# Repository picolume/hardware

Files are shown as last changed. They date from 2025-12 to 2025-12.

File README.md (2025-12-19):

# PicoLume Hardware

Hardware designs for the PicoLume wireless LED prop system. All designs are created in KiCad.

## Design Series

### series-prop (Primary)

The primary hardware design for production use. Contains the **PicoLume Board** - a compact control board designed to be installed on each prop in a synchronized LED light show.

**Current Design: receiver-v1**

An RP2040-based control board featuring:

- RP2040 microcontroller with 16MB flash (W25Q16JVS)
- RFM69HCW radio module (915 MHz) for wireless timecode reception
- USB-C connector for programming and show file upload
- Dual power input with automatic switching (LM66200)
- 5V buck converter (AP63205WU) for LED strip power
- Pinout for 0.91" OLED display (I2C)
- Screw terminals for LED strip connection (WS2812B)
- Level shifter (74AHCT1G125) for reliable LED data signal
- Three tactile buttons for configuration
- Onboard WS2812B status LED
- Four M3 mounting holes

The PicoLume Board is the core control component. A complete receiver or transmitter setup requires additional hardware (enclosures, power supplies, antennas, etc.) which are currently being designed.

### series-legacy (Prototypes)

Early prototype designs from the development phase. These boards were used for proof-of-concept testing and firmware development.

**Note:** These designs are prototypes and are not suited for production use.

| Version | Description |
| --- | --- |
| v1 | Initial RFM69-based design |
| v2 | RP2040 with Pi Pico footprint |
| v3 | Refined RP2040 design |
| v4 | RP2350 Experiment |

## Related Repositories

- **firmware/** - Arduino firmware for receiver and remote devices

## License

See [LICENSE](LICENSE) for details.

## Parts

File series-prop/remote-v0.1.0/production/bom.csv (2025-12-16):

Designator | Footprint | Quantity | Value | LCSC Part #
C1, C20, C22 | 0805 | 3 | 22u | C45783
C10, C8 | 0603 | 2 | 1u | C15849
C11, C12, C13, C14, C15, C16, C19, C21, C5, C6, C7, C9 | 0603 | 12 | 100n | C14663
C17 | 0603 | 1 | 10u | C14663
C18, C26 | 1206 | 2 | 10u | C13585
C2, C3 | 0603 | 2 | 30p | C1658
C4 | CP_Elec_8x10 | 1 | 220uF | C2164649
D1 | 0603 | 1 | LED | C2286
D2 | LED_WS2812B-2020_PLCC4_2.0x2.0mm | 1 | WS2812B-2020 | C965555
F1 | 1206 | 1 | Polyfuse | C207036
H1, H2, H3, H4 | MountingHole_3.2mm_M3 | 4 | MountingHole
IC1 | LM66200DRLR | 1 | LM66200DRLR | C3235556
J1, J4 | PinHeader_1x17_P2.54mm_Vertical | 2 | Conn_01x17
J10 | PinHeader_1x03_P2.54mm_Vertical | 1 | Conn_01x03_Pin
J11, J2 | PinHeader_1x04_P2.54mm_Vertical | 2 | Conn_01x04_Pin
J13 | USB_C_Receptacle_HRO_TYPE-C-31-M-12 | 1 | USB_C_Receptacle_USB2.0_16P | C165948
J5 | PinHeader_1x01_P2.54mm_Vertical | 1 | Conn_01x01_Pin
J6 | TerminalBlock_bornier-2_P5.08mm | 1 | Screw_Terminal_01x02
J7 | TerminalBlock_bornier-3_P5.08mm | 1 | Screw_Terminal_01x03
J8 | U.FL_Hirose_U.FL-R-SMT-1_Vertical | 1 | Conn_Coaxial | C88374
J9 | CONN_SM04B-SRSS-TB_JST | 1 | SM04B-SRSS-TB
L2 | L_Sunlord_SWPA4030S | 1 | 4.7u | C57269
R1 | 0603 | 1 | 1k | C21190
R10, R11 | 0603 | 2 | 5.1k | C23186
R15 | 0603 | 1 | 330R | C23138
R2, R21, R6, R7, R8, R9 | 0603 | 6 | 10K | C25804
R3, R4 | 0603 | 2 | 27 | C22941
R5 | 0603 | 1 | 1k
SW1, SW2, SW3 | SW_Tactile_SPST_NO_Straight_CK_PTS636Sx25SMTRLFS | 3 | SW_Push | C609852
U1 | SOT-23-5 | 1 | RT9080-33GJ5 | C841192
U2 | SOIC-8_5.3x5.3mm_P1.27mm | 1 | W25Q16JVS | C131025
U3 | QFN-56-1EP_7x7mm_P0.4mm_EP3.2x3.2mm | 1 | RP2040 | C2040
U4 | HOPERF_RFM9XW_SMD | 1 | RFM69HCW | C2844478
U5 | TSOT-23-6 | 1 | AP63205WU | C2071056
U6 | SOT-23-5 | 1 | 74AHCT1G125 | C7484
U7 | 3544-2 | 1 | 3544-2
Y1 | Crystal_SMD_3225-4Pin_3.2x2.5mm | 1 | Crystal_GND24 | C9002

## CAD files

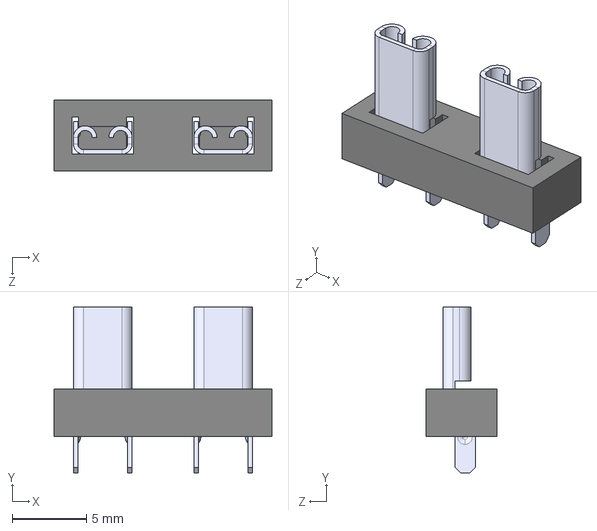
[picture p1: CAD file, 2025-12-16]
series-prop/remote-v0.1.0/3D/3544-2.stp
14.7 x 11.2 x 4.75 mm

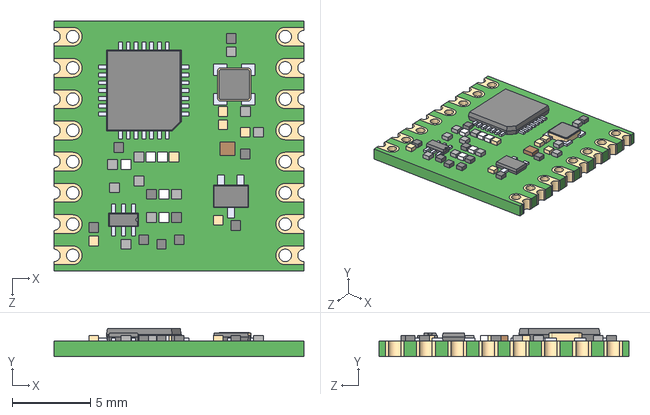
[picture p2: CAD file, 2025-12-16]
series-prop/remote-v0.1.0/3D/RFM69HCW.STEP
16.0 x 1.80 x 16.0 mm

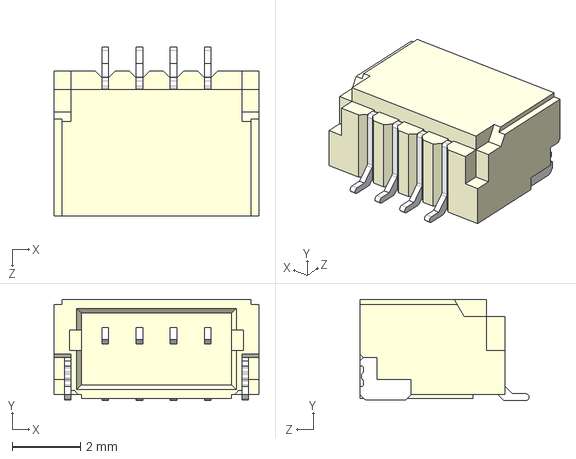
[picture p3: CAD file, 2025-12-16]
series-prop/remote-v0.1.0/3D/SM04B-SRSS-TB.STEP
6.00 x 2.96 x 4.95 mm

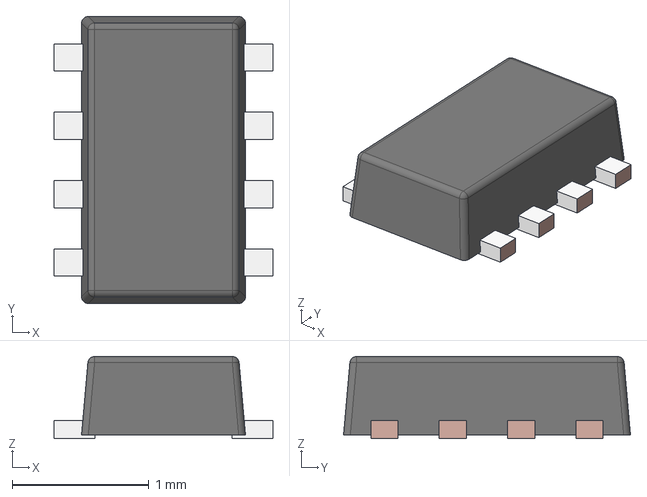
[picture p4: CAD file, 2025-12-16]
series-prop/remote-v0.1.0/3D/LM66200DRLR.stp
1.60 x 2.10 x 0.6 mm
FRAME-DRL0008A
BODY-SOT

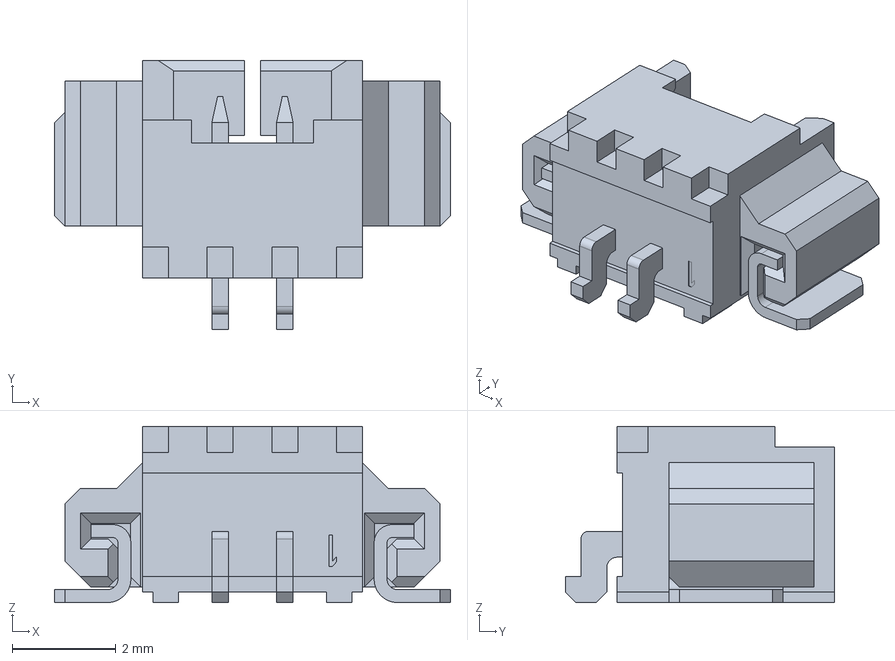
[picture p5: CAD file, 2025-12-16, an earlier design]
series-legacy/v4/3D_Models/53261-0271.stp
7.65 x 5.20 x 3.40 mm

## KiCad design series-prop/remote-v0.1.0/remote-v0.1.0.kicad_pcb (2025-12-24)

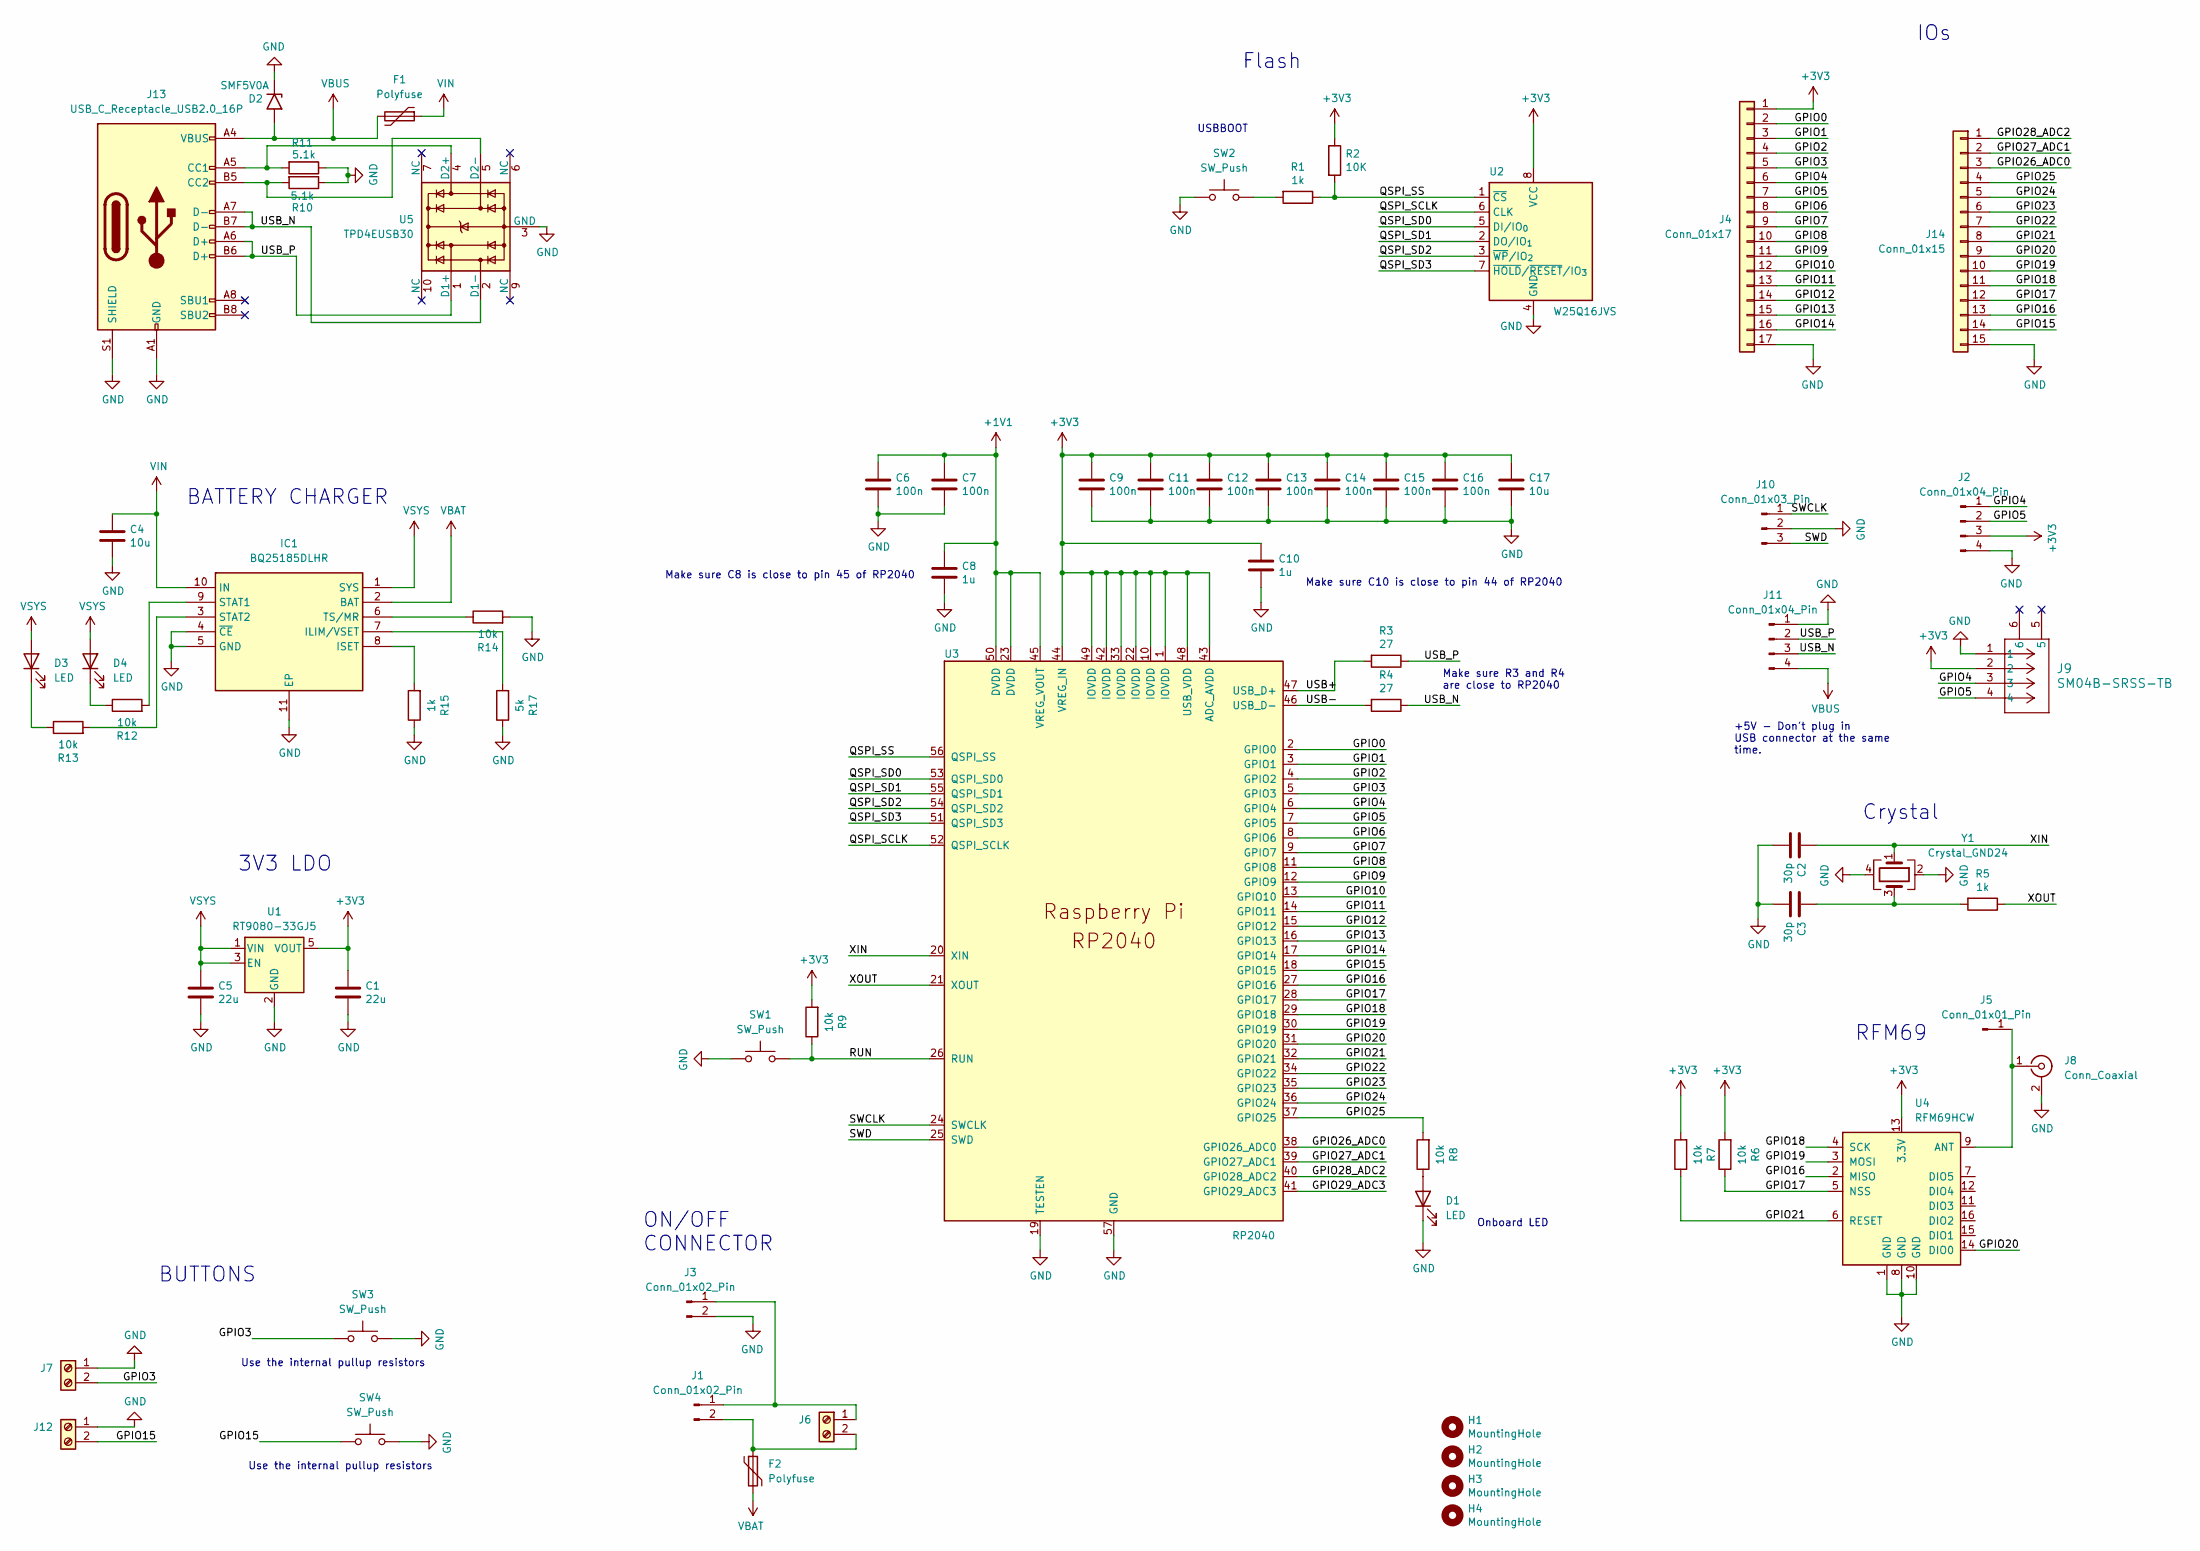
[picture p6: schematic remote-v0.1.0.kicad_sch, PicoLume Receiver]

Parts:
C1, C5: 22u; C_0805_2012Metric; LCSC C45783
C2, C3: 30p; C_0603_1608Metric; LCSC C1658
C4, C17: 10u; C_0603_1608Metric; LCSC C14663
C6, C7, C9, C11, C12, C13, C14, C15, C16: 100n; C_0603_1608Metric; LCSC C14663
C8, C10: 1u; C_0603_1608Metric; LCSC C15849
D1, D3, D4: LED; LED_0603_1608Metric; LCSC C2286
D2: SMF5V0A; D_SMF; LCSC C151296
F1, F2: Polyfuse; Fuse_1210_3225Metric; LCSC C20617440
H1, H2, H3, H4: MountingHole; MountingHole_3.2mm_M3
IC1: BQ25185DLHR; SON40P220X200X80-11N; Mouser Part Number 595-BQ25185DLHR
J1: Conn_01x02_Pin; PinHeader_1x02_P2.54mm_Vertical
J2, J11: Conn_01x04_Pin; PinHeader_1x04_P2.54mm_Vertical
J3: Conn_01x02_Pin; JST_PH_S2B-PH-K_1x02_P2.00mm_Horizontal
J4: Conn_01x17; PinHeader_1x17_P2.54mm_Vertical
J5: Conn_01x01_Pin; PinHeader_1x01_P2.54mm_Vertical
J6, J7, J12: Screw_Terminal_01x02; TerminalBlock_bornier-2_P5.08mm
J8: Conn_Coaxial; U.FL_Hirose_U.FL-R-SMT-1_Vertical; LCSC C88374
J9: SM04B-SRSS-TB; CONN_SM04B-SRSS-TB_JST
J10: Conn_01x03_Pin; PinHeader_1x03_P2.54mm_Vertical
J13: USB_C_Receptacle_USB2.0_16P; USB_C_Receptacle_HRO_TYPE-C-31-M-12; LCSC C165948
J14: Conn_01x15; PinHeader_1x15_P2.54mm_Vertical
R1, R15: 1k; R_0603_1608Metric; LCSC C21190
R2: 10K; R_0603_1608Metric; LCSC C25804
R3, R4: 27; R_0603_1608Metric; LCSC C22941
R5: 1k; R_0603_1608Metric
R6, R7, R8, R9, R12, R13, R14: 10k; R_0603_1608Metric; LCSC C25804
R10, R11: 5.1k; R_0603_1608Metric; LCSC C23186
R17: 5k; R_0603_1608Metric; LCSC C166926
SW1, SW2, SW3, SW4: SW_Push; SW_Tactile_SPST_NO_Straight_CK_PTS636Sx25SMTRLFS; LCSC C609852
U1: RT9080-33GJ5; SOT-23-5; LCSC C841192
U2: W25Q16JVS; SOIC-8_5.3x5.3mm_P1.27mm; LCSC C131025
U3: RP2040; QFN-56-1EP_7x7mm_P0.4mm_EP3.2x3.2mm; LCSC C2040
U4: RFM69HCW; HOPERF_RFM9XW_SMD; LCSC C2844478
U5: TPD4EUSB30; USON-10_2.5x1.0mm_P0.5mm; LCSC C90627
Y1: Crystal_GND24; Crystal_SMD_3225-4Pin_3.2x2.5mm; LCSC C9002

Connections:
+1V1: C6.1, C7.1, C8.1, U3.23 (DVDD), U3.45 (VREG_VOUT), U3.50 (DVDD)
+3V3: C1.1, C9.1, C10.1, C11.1, C12.1, C13.1, C14.1, C15.1, C16.1, C17.1, J2.3, J4.1, J9.2, R2.1, R6.2, R7.2, R9.2, U1.5 (VOUT), U2.8 (VCC), U3.1 (IOVDD), U3.10 (IOVDD), U3.22 (IOVDD), U3.33 (IOVDD), U3.42 (IOVDD), U3.43 (ADC_AVDD), U3.44 (VREG_IN), U3.48 (USB_VDD), U3.49 (IOVDD), U4.13 (3.3V)
/GPIO0: J4.2, U3.2 (GPIO0)
/GPIO1: J4.3, U3.3 (GPIO1)
/GPIO2: J4.4, U3.4 (GPIO2)
/GPIO3: J4.5, J7.2, SW3.2, U3.5 (GPIO3)
/GPIO4: J2.1, J4.6, J9.3, U3.6 (GPIO4)
/GPIO5: J2.2, J4.7, J9.4, U3.7 (GPIO5)
/GPIO6: J4.8, U3.8 (GPIO6)
/GPIO7: J4.9, U3.9 (GPIO7)
/GPIO8: J4.10, U3.11 (GPIO8)
/GPIO9: J4.11, U3.12 (GPIO9)
/GPIO10: J4.12, U3.13 (GPIO10)
/GPIO11: J4.13, U3.14 (GPIO11)
/GPIO12: J4.14, U3.15 (GPIO12)
/GPIO13: J4.15, U3.16 (GPIO13)
/GPIO14: J4.16, U3.17 (GPIO14)
/GPIO15: J12.2, J14.14, SW4.2, U3.18 (GPIO15)
/GPIO16: J14.13, U3.27 (GPIO16), U4.2 (MISO)
/GPIO17: J14.12, R6.1, U3.28 (GPIO17), U4.5 (NSS)
/GPIO18: J14.11, U3.29 (GPIO18), U4.4 (SCK)
/GPIO19: J14.10, U3.30 (GPIO19), U4.3 (MOSI)
/GPIO20: J14.9, U3.31 (GPIO20), U4.14 (DIO0)
/GPIO21: J14.8, R7.1, U3.32 (GPIO21), U4.6 (RESET)
/GPIO22: J14.7, U3.34 (GPIO22)
/GPIO23: J14.6, U3.35 (GPIO23)
/GPIO24: J14.5, U3.36 (GPIO24)
/GPIO25: J14.4, R8.2, U3.37 (GPIO25)
/GPIO26_ADC0: J14.3, U3.38 (GPIO26_ADC0)
/GPIO27_ADC1: J14.2, U3.39 (GPIO27_ADC1)
/GPIO28_ADC2: J14.1, U3.40 (GPIO28_ADC2)
/GPIO29_ADC3: U3.41 (GPIO29_ADC3)
/QSPI_SCLK: U2.6 (CLK), U3.52 (QSPI_SCLK)
/QSPI_SD0: U2.5 (DI/IO_{0}), U3.53 (QSPI_SD0)
/QSPI_SD1: U2.2 (DO/IO_{1}), U3.55 (QSPI_SD1)
/QSPI_SD2: U2.3 (~WP/IO_{2}), U3.54 (QSPI_SD2)
/QSPI_SD3: U2.7 (~HOLD/~RESET/IO_{3}), U3.51 (QSPI_SD3)
/QSPI_SS: R1.1, R2.2, U2.1 (~CS), U3.56 (QSPI_SS)
/RUN: R9.1, SW1.2, U3.26 (RUN)
/SWCLK: J10.1, U3.24 (SWCLK)
/SWD: J10.3, U3.25 (SWD)
/USB+: R3.2, U3.47 (USB_D+)
/USB-: R4.2, U3.46 (USB_D-)
/USB_N: J11.3, J13.A7 (D-), J13.B7 (D-), R4.1, U5.2 (D1-)
/USB_P: J11.2, J13.A6 (D+), J13.B6 (D+), R3.1, U5.1 (D1+)
/XIN: C2.1, U3.20 (XIN), Y1.1
/XOUT: R5.1, U3.21 (XOUT)
GND: C1.2, C2.2, C3.2, C4.2, C5.2, C6.2, C7.2, C8.2, C9.2, C10.2, C11.2, C12.2, C13.2, C14.2, C15.2, C16.2, C17.2, D1.1 (K), D2.1 (A1), IC1.4 (~CE), IC1.5 (GND), IC1.11 (EP), J2.4, J3.2, J4.17, J7.1, J8.2 (Ext), J9.1, J10.2, J11.1, J12.1, J13.A1 (GND), J13.A12 (GND), J13.B1 (GND), J13.B12 (GND), J13.S1 (SHIELD), J14.15, R10.1, R11.1, R14.2, R15.1, R17.1, SW1.1, SW2.1, SW3.1, SW4.1, U1.2 (GND), U2.4 (GND), U3.19 (TESTEN), U3.57 (GND), U4.1 (GND), U4.8 (GND), U4.10 (GND), U5.3 (GND), U5.8 (GND), Y1.2, Y1.4
unnamed: C3.1, R5.2, Y1.3
unnamed: D1.2 (A), R8.1
unnamed: D3.1 (K), R13.1
unnamed: D4.1 (K), R12.1
unnamed: IC1.7 (ILIM/VSET), R17.2
unnamed: IC1.8 (ISET), R15.2
unnamed: IC1.9 (STAT1), R12.2
unnamed: IC1.3 (STAT2), R13.2
unnamed: IC1.6 (TS/MR), R14.1
unnamed: J1.1, J3.1, J6.1
unnamed: F2.1, J1.2, J6.2
unnamed: J5.1, J8.1 (In), U4.9 (ANT)
unnamed: J13.A5 (CC1), R11.2, U5.4 (D2+)
unnamed: J13.B5 (CC2), R10.2, U5.5 (D2-)
unnamed: R1.2, SW2.2
VBAT: F2.2, IC1.2 (BAT)
VBUS: D2.2 (A2), F1.2, J11.4, J13.A4 (VBUS), J13.A9 (VBUS), J13.B4 (VBUS), J13.B9 (VBUS)
VIN: C4.1, F1.1, IC1.10 (IN)
VSYS: C5.1, D3.2 (A), D4.2 (A), IC1.1 (SYS), U1.1 (VIN), U1.3 (EN)

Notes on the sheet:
Use the internal pullup resistors
RFM69
IOs
Crystal
Make sure C8 is close to pin 45 of RP2040
+5V - Don't plug in USB connector at the same time.
BUTTONS
USBBOOT
Make sure C10 is close to pin 44 of RP2040
ON/OFF CONNECTOR
Onboard LED
BATTERY CHARGER
3V3 LDO
Make sure R3 and R4 are close to RP2040
Flash

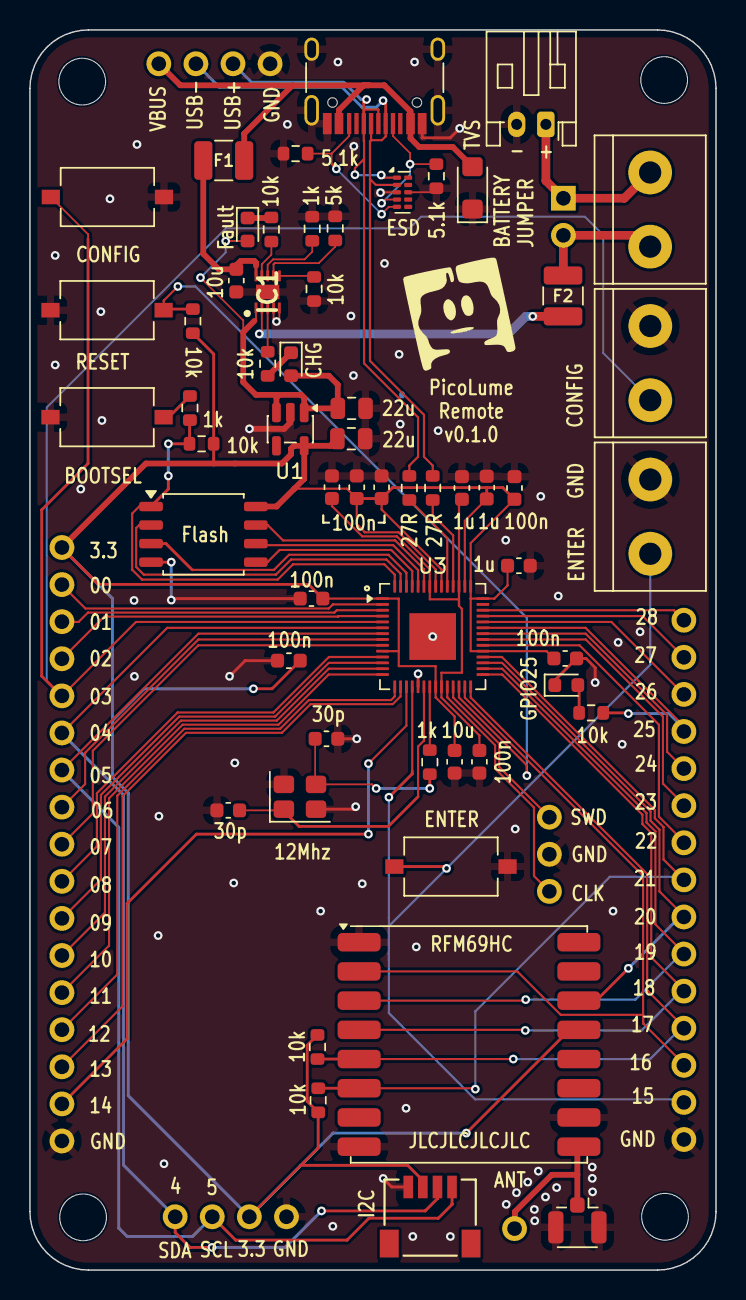
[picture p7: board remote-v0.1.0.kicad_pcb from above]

Board: 2 copper layers, 47.0 x 84.9 mm, 68 parts (0 on the bottom side), 66 nets.

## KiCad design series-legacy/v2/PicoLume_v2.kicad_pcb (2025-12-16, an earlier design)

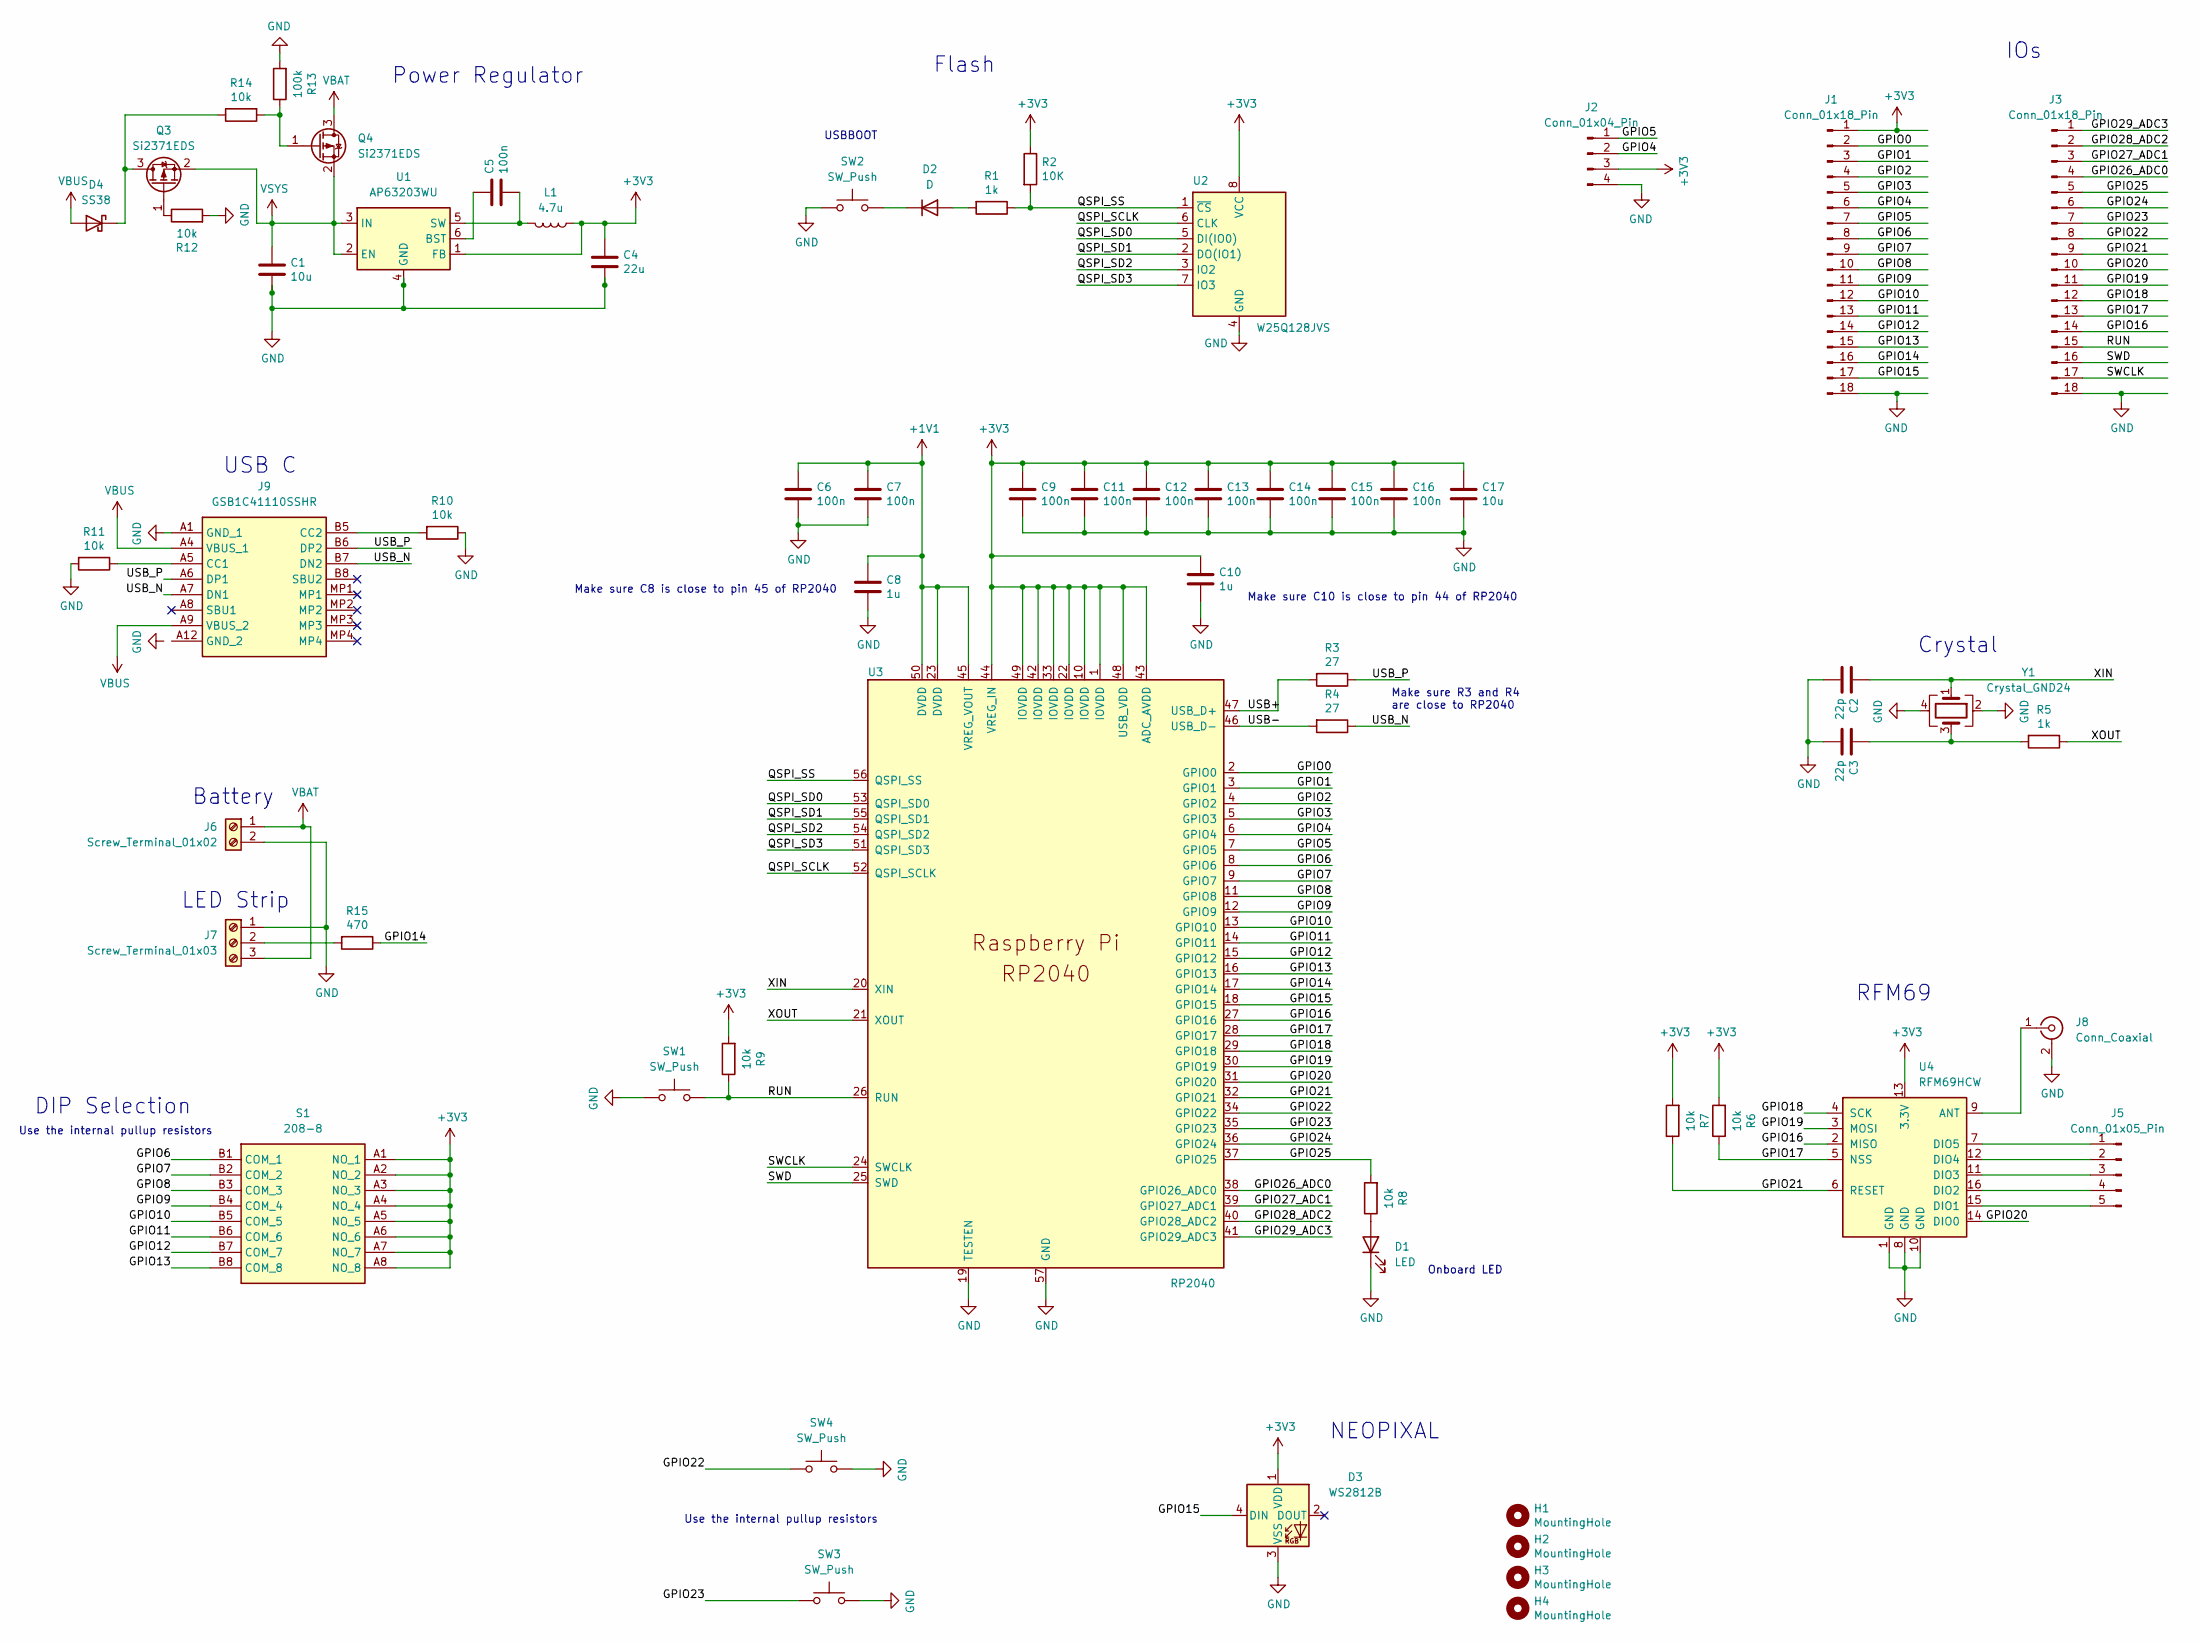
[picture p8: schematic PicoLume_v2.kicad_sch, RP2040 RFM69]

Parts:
C1, C17: 10u; C_0603_1608Metric
C2, C3: 22p; C_0603_1608Metric
C4: 22u; C_0603_1608Metric
C5, C6, C7, C9, C11, C12, C13, C14, C15, C16: 100n; C_0603_1608Metric
C8, C10: 1u; C_0603_1608Metric
D1: LED; LED_0603_1608Metric
D2: D; D_0603_1608Metric
D3: WS2812B; LED_WS2812B_PLCC4_5.0x5.0mm_P3.2mm
D4: SS38; D_SMA
H1, H2, H3, H4: MountingHole; MountingHole_2.7mm_M2.5
J1, J3: Conn_01x18_Pin; PinHeader_1x18_P2.54mm_Vertical
J2: Conn_01x04_Pin; PinHeader_1x04_P2.54mm_Vertical
J5: Conn_01x05_Pin; PinHeader_1x05_P2.54mm_Vertical
J6: Screw_Terminal_01x02; TerminalBlock_bornier-2_P5.08mm
J7: Screw_Terminal_01x03; TerminalBlock_bornier-3_P5.08mm
J8: Conn_Coaxial; U.FL_Molex_MCRF_73412-0110_Vertical
J9: GSB1C41110SSHR; Manufacturer_Part_Number GSB1C41110SSHR
L1: 4.7u; VLS5045EX330M
Q3, Q4: Si2371EDS; SOT-23
R1, R5: 1k; R_0603_1608Metric
R2: 10K; R_0603_1608Metric
R3, R4: 27; R_0603_1608Metric
R6, R7, R8, R9, R10, R11, R12, R14: 10k; R_0603_1608Metric
R13: 100k; R_0603_1608Metric
R15: 470; R_0603_1608Metric
S1: 208-8; 2088; Mouser Part Number 774-2088
SW1, SW2, SW3, SW4: SW_Push; FSMH
U1: AP63203WU; TSOT-23-6
U2: W25Q128JVS; SOIC-8_5.23x5.23mm_P1.27mm
U3: RP2040; RP2040-QFN-56
U4: RFM69HCW; MOD_COM-13909
Y1: Crystal_GND24; ABM810000MHZ12D2W

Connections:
+1V1: C6.1, C7.1, C8.1, U3.23 (DVDD), U3.45 (VREG_VOUT), U3.50 (DVDD)
+3V3: C4.1, C9.1, C10.1, C11.1, C12.1, C13.1, C14.1, C15.1, C16.1, C17.1, D3.1 (VDD), J1.1, J2.3, L1.1, R2.1, R6.2, R7.2, R9.2, S1.A1 (NO_1), S1.A2 (NO_2), S1.A3 (NO_3), S1.A4 (NO_4), S1.A5 (NO_5), S1.A6 (NO_6), S1.A7 (NO_7), S1.A8 (NO_8), U1.1 (FB), U2.8 (VCC), U3.1 (IOVDD), U3.10 (IOVDD), U3.22 (IOVDD), U3.33 (IOVDD), U3.42 (IOVDD), U3.43 (ADC_AVDD), U3.44 (VREG_IN), U3.48 (USB_VDD), U3.49 (IOVDD), U4.13 (3.3V)
/GPIO0: J1.2, U3.2 (GPIO0)
/GPIO1: J1.3, U3.3 (GPIO1)
/GPIO2: J1.4, U3.4 (GPIO2)
/GPIO3: J1.5, U3.5 (GPIO3)
/GPIO4: J1.6, J2.2, U3.6 (GPIO4)
/GPIO5: J1.7, J2.1, U3.7 (GPIO5)
/GPIO6: J1.8, S1.B1 (COM_1), U3.8 (GPIO6)
/GPIO7: J1.9, S1.B2 (COM_2), U3.9 (GPIO7)
/GPIO8: J1.10, S1.B3 (COM_3), U3.11 (GPIO8)
/GPIO9: J1.11, S1.B4 (COM_4), U3.12 (GPIO9)
/GPIO10: J1.12, S1.B5 (COM_5), U3.13 (GPIO10)
/GPIO11: J1.13, S1.B6 (COM_6), U3.14 (GPIO11)
/GPIO12: J1.14, S1.B7 (COM_7), U3.15 (GPIO12)
/GPIO13: J1.15, S1.B8 (COM_8), U3.16 (GPIO13)
/GPIO14: J1.16, R15.1, U3.17 (GPIO14)
/GPIO15: D3.4 (DIN), J1.17, U3.18 (GPIO15)
/GPIO16: J3.14, U3.27 (GPIO16), U4.2 (MISO)
/GPIO17: J3.13, R6.1, U3.28 (GPIO17), U4.5 (NSS)
/GPIO18: J3.12, U3.29 (GPIO18), U4.4 (SCK)
/GPIO19: J3.11, U3.30 (GPIO19), U4.3 (MOSI)
/GPIO20: J3.10, U3.31 (GPIO20), U4.14 (DIO0)
/GPIO21: J3.9, R7.1, U3.32 (GPIO21), U4.6 (RESET)
/GPIO22: J3.8, SW4.2, U3.34 (GPIO22)
/GPIO23: J3.7, SW3.2, U3.35 (GPIO23)
/GPIO24: J3.6, U3.36 (GPIO24)
/GPIO25: J3.5, R8.2, U3.37 (GPIO25)
/GPIO26_ADC0: J3.4, U3.38 (GPIO26_ADC0)
/GPIO27_ADC1: J3.3, U3.39 (GPIO27_ADC1)
/GPIO28_ADC2: J3.2, U3.40 (GPIO28_ADC2)
/GPIO29_ADC3: J3.1, U3.41 (GPIO29_ADC3)
/QSPI_SCLK: U2.6 (CLK), U3.52 (QSPI_SCLK)
/QSPI_SD0: U2.5 (DI(IO0)), U3.53 (QSPI_SD0)
/QSPI_SD1: U2.2 (DO(IO1)), U3.55 (QSPI_SD1)
/QSPI_SD2: U2.3 (IO2), U3.54 (QSPI_SD2)
/QSPI_SD3: U2.7 (IO3), U3.51 (QSPI_SD3)
/QSPI_SS: R1.1, R2.2, U2.1 (~CS), U3.56 (QSPI_SS)
/RUN: J3.15, R9.1, SW1.2, U3.26 (RUN)
/SWCLK: J3.17, U3.24 (SWCLK)
/SWD: J3.16, U3.25 (SWD)
/USB+: R3.2, U3.47 (USB_D+)
/USB-: R4.2, U3.46 (USB_D-)
/USB_N: J9.A7 (DN1), J9.B7 (DN2), R4.1
/USB_P: J9.A6 (DP1), J9.B6 (DP2), R3.1
/XIN: C2.1, U3.20 (XIN), Y1.1
/XOUT: R5.1, U3.21 (XOUT)
GND: C1.2, C2.2, C3.2, C4.2, C6.2, C7.2, C8.2, C9.2, C10.2, C11.2, C12.2, C13.2, C14.2, C15.2, C16.2, C17.2, D1.1 (K), D3.3 (VSS), J1.18, J2.4, J3.18, J6.2, J7.1, J8.2 (Ext), J9.A1 (GND_1), R10.1, R11.2, R12.2, R13.2, SW1.1, SW2.1, SW3.1, SW4.1, U1.4 (GND), U2.4 (GND), U3.19 (TESTEN), U3.57 (GND), U4.1 (GND), U4.8 (GND), U4.10 (GND), Y1.2, Y1.4
unnamed: C3.1, R5.2, Y1.3
unnamed: D1.2 (A), R8.1
unnamed: D2.2 (A), R1.2
unnamed: D2.1 (K), SW2.2
unnamed: D4.1 (K), Q3.3 (D), R14.1
unnamed: J5.1, U4.7 (DIO5)
unnamed: J5.2, U4.12 (DIO4)
unnamed: J5.3, U4.11 (DIO3)
unnamed: J5.4, U4.16 (DIO2)
unnamed: J5.5, U4.15 (DIO1)
unnamed: J7.2, R15.2
unnamed: J8.1 (In), U4.9 (ANT)
unnamed: J9.A5 (CC1), R11.1
unnamed: J9.B5 (CC2), R10.2
unnamed: Q3.1 (G), R12.1
unnamed: Q4.1 (G), R13.1, R14.2
unnamed: C5.1, U1.6 (BST)
unnamed: C5.2, L1.2, U1.5 (SW)
VBAT: J6.1, J7.3, Q4.3 (D)
VBUS: D4.2 (A), J9.A4 (VBUS_1), J9.A9 (VBUS_2)
VSYS: C1.1, Q3.2 (S), Q4.2 (S), U1.2 (EN), U1.3 (IN)

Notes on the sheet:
DIP Selection
Use the internal pullup resistors
NEOPIXAL
RFM69
IOs
Crystal
USB C
Make sure C8 is close to pin 45 of RP2040
Battery
LED Strip
USBBOOT
Power Regulator
Make sure C10 is close to pin 44 of RP2040
Onboard LED
Make sure R3 and R4 are close to RP2040
Flash

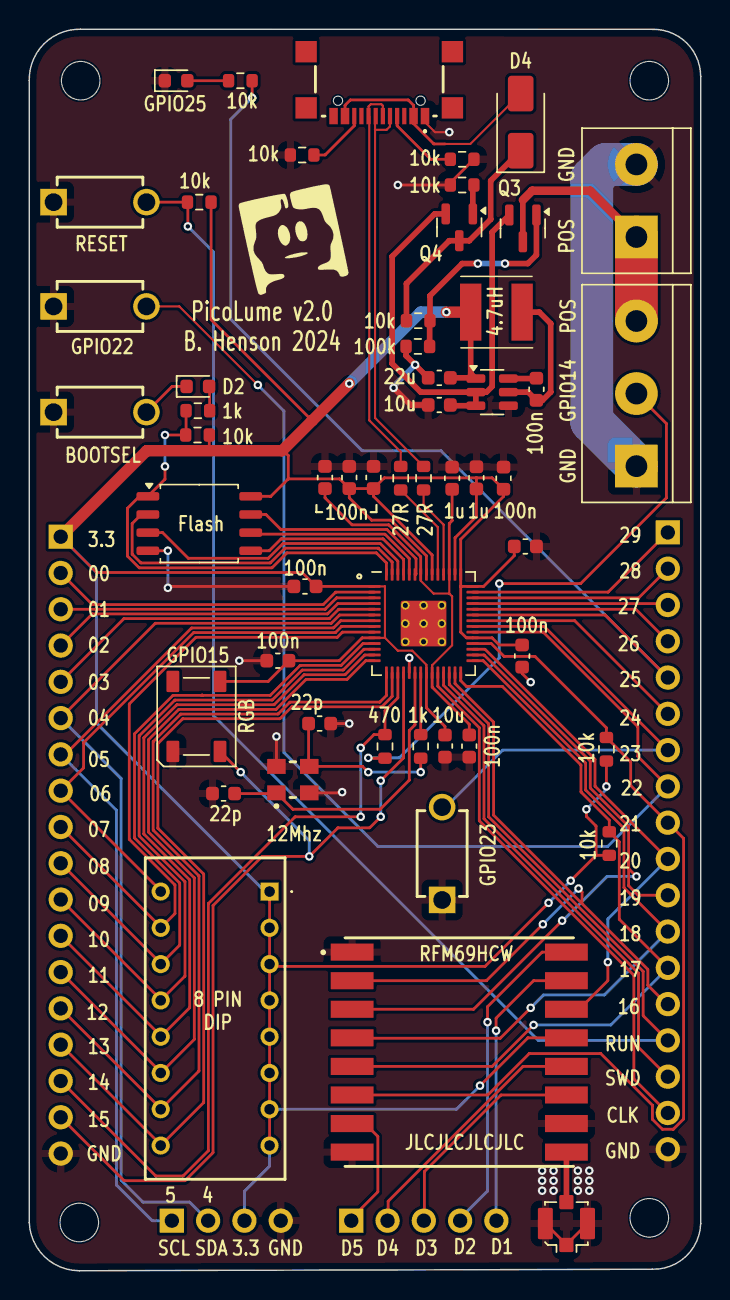
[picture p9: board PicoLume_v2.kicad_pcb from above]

Board: 2 copper layers, 47.0 x 86.9 mm, 61 parts (0 on the bottom side), 69 nets.

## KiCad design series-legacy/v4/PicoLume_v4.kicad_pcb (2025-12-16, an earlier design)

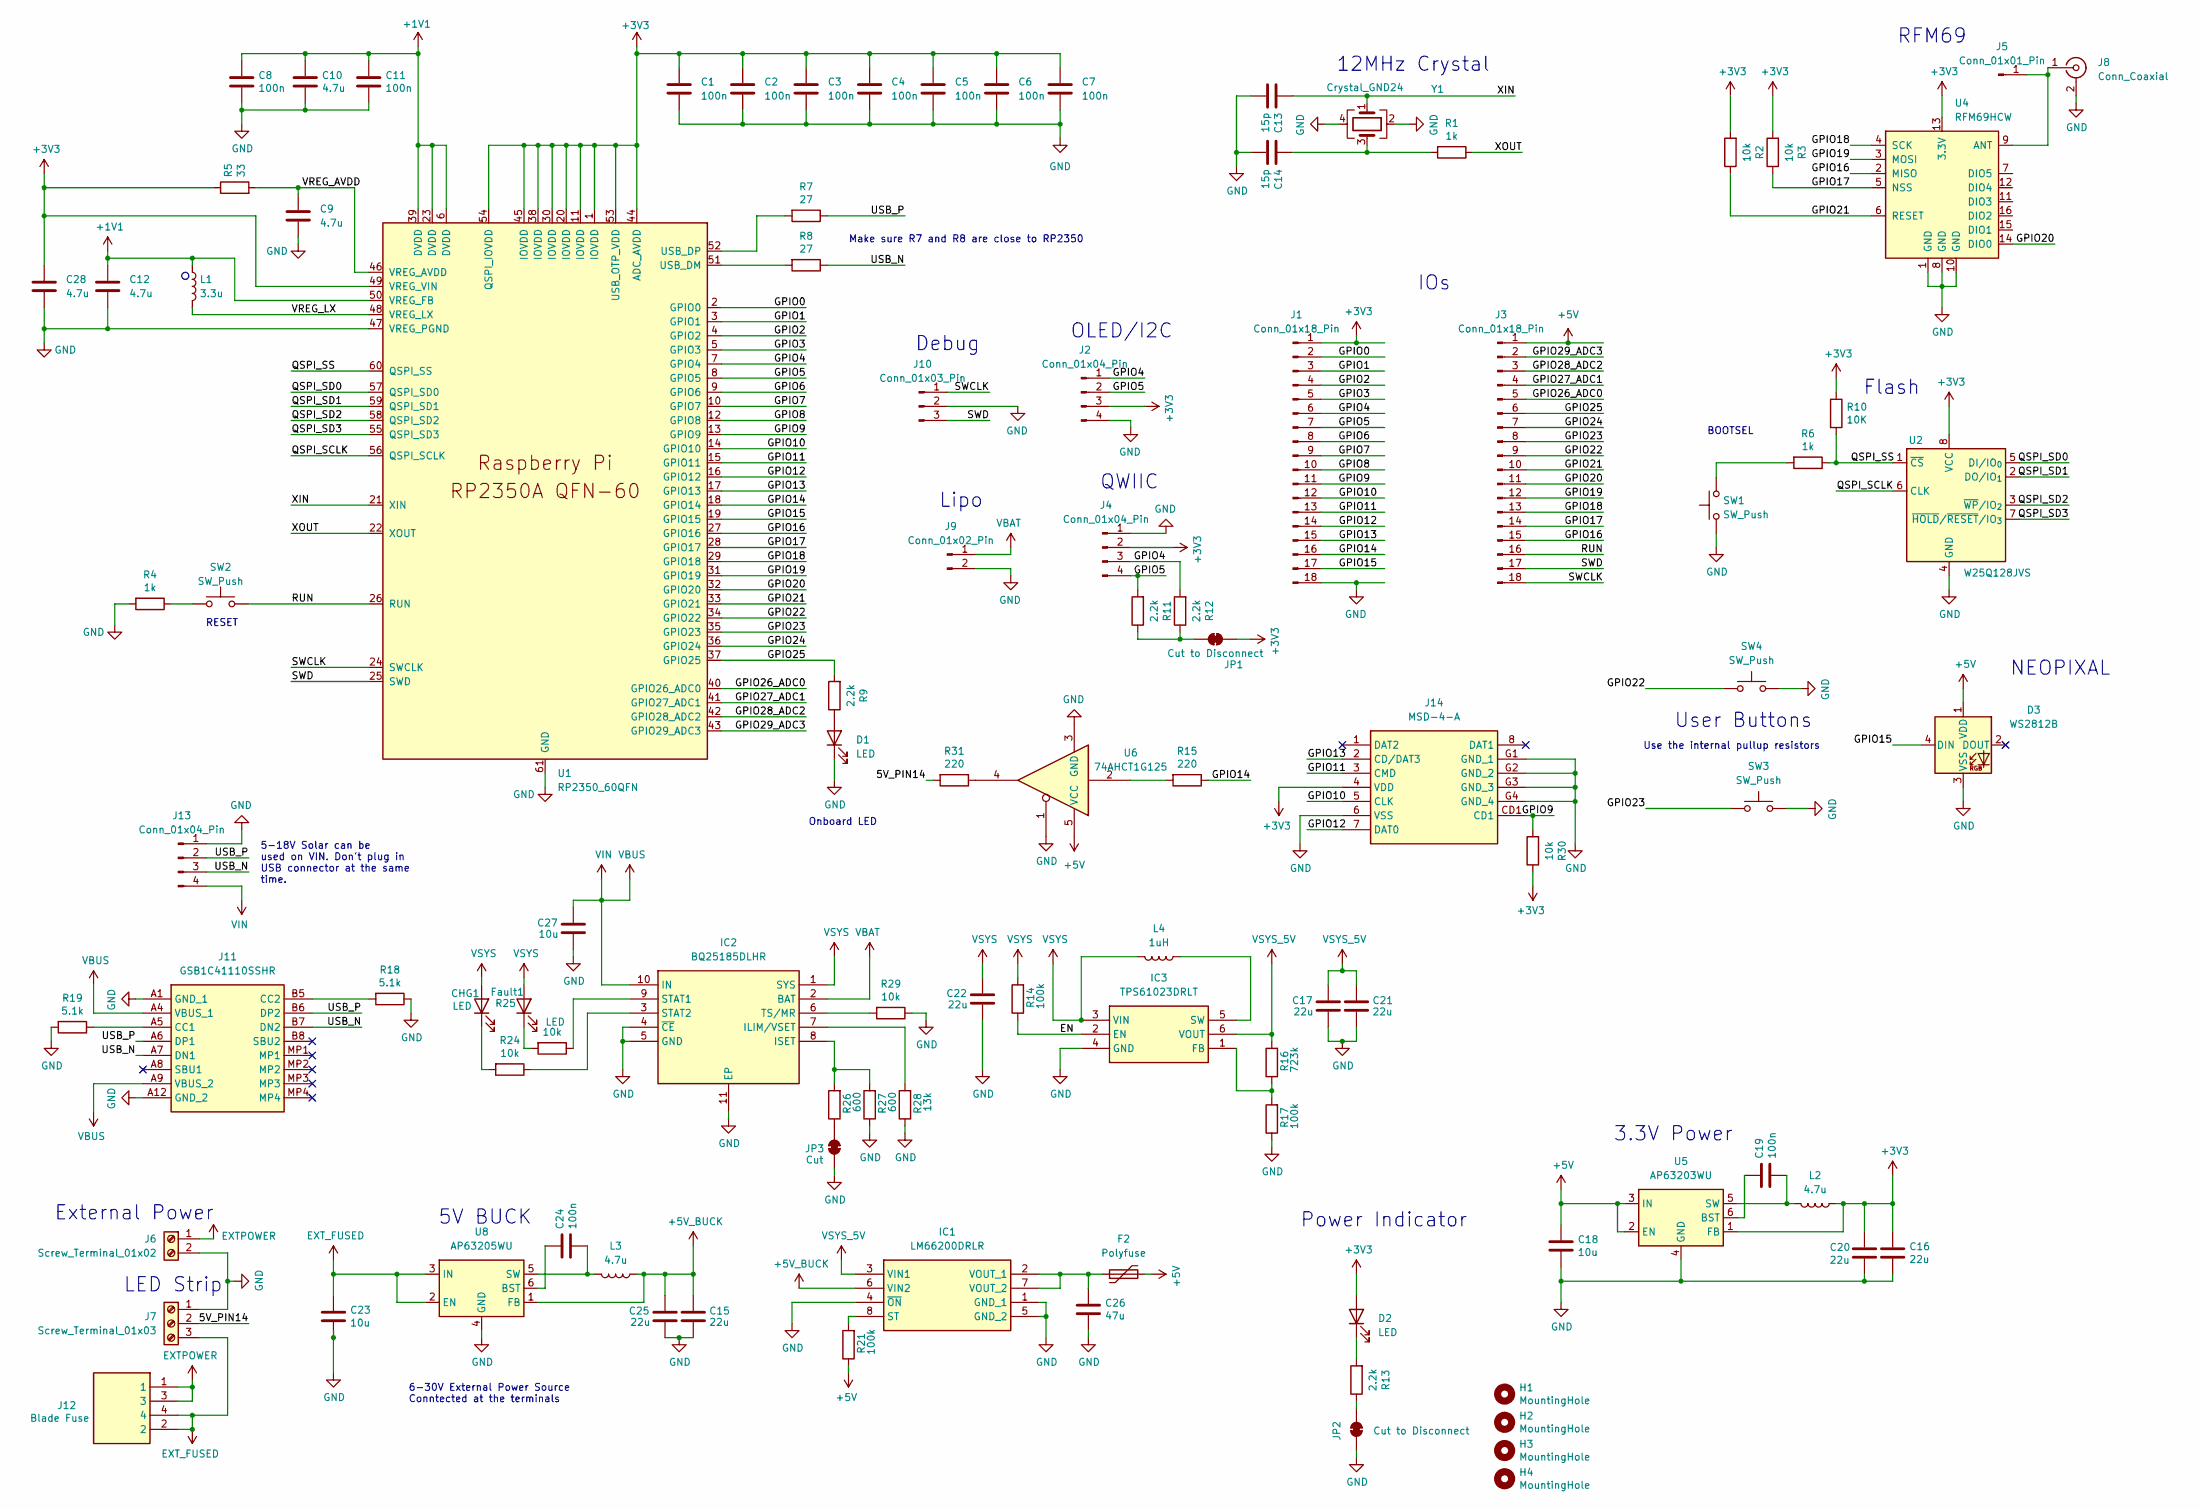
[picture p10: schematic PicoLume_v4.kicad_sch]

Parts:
C1, C2, C3, C4, C5, C6, C7, C8, C11, C19, C24: 100n; C_0603_1608Metric
C9, C10, C12, C28: 4.7u; C_0603_1608Metric
C13, C14: 15p; C_0603_1608Metric
C15, C16, C17, C20, C21, C22, C25: 22u; C_0805_2012Metric
C18: 10u; C_0805_2012Metric
C23: 10u; C_1206_3216Metric
C26: 47u; C_1206_3216Metric
C27: 10u; C_0603_1608Metric
CHG1: LED; LED_0603_1608Metric
D1, D2: LED; LED_0603_1608Metric
D3: WS2812B; INPI15TAT5R5G5B
F2: Polyfuse; 1206L075132WR
Fault1: LED; LED_0603_1608Metric
H1, H2, H3, H4: MountingHole; MountingHole_3.2mm_M3
IC1: LM66200DRLR; SOTFL50P160X60-8N; Mouser Part Number 595-LM66200DRLR
IC2: BQ25185DLHR; SON40P220X200X80-11N; Mouser Part Number 595-BQ25185DLHR
IC3: TPS61023DRLT; SOTFL50P160X60-6N; Mouser Part Number 595-TPS61023DRLT
J1, J3: Conn_01x18_Pin; PinHeader_1x18_P2.54mm_Vertical
J2, J13: Conn_01x04_Pin; PinHeader_1x04_P2.54mm_Vertical
J4: Conn_01x04_Pin; JST_SH_SM04B-SRSS-TB_1x04-1MP_P1.00mm_Horizontal
J5: Conn_01x01_Pin; PinHeader_1x01_P2.54mm_Vertical
J6: Screw_Terminal_01x02; TerminalBlock_bornier-2_P5.08mm
J7: Screw_Terminal_01x03; TerminalBlock_bornier-3_P5.08mm
J8: Conn_Coaxial; U.FL_Molex_MCRF_73412-0110_Vertical
J9: Conn_01x02_Pin; JST_PH_S2B-PH-K_1x02_P2.00mm_Horizontal
J10: Conn_01x03_Pin; JST_SH_BM03B-SRSS-TB_1x03-1MP_P1.00mm_Vertical
J11: GSB1C41110SSHR; Manufacturer_Part_Number GSB1C41110SSHR
J12: Blade Fuse; 35222; Mouser Part Number 534-3522-2
J14: MSD-4-A; MSD4A; Mouser Part Number 179-MSD-4-A
JP1, JP2: Cut to Disconnect; SolderJumper-2_P1.3mm_Bridged_RoundedPad1.0x1.5mm
JP3: Cut; SolderJumper-2_P1.3mm_Bridged_RoundedPad1.0x1.5mm
L1: 3.3u; AOTAB201610S3R3101T
L2, L3: 4.7u; L_1210_3225Metric
L4: 1uH; L_1210_3225Metric
R1, R4, R6: 1k; R_0603_1608Metric
R2, R3, R24, R25, R29, R30: 10k; R_0603_1608Metric
R5: 33; R_0603_1608Metric
R7, R8: 27; R_0603_1608Metric
R9, R11, R12, R13: 2.2k; R_0603_1608Metric
R10: 10K; R_0603_1608Metric
R14, R17, R21: 100k; R_0603_1608Metric
R15, R31: 220; R_0603_1608Metric
R16: 723k; R_0603_1608Metric
R18, R19: 5.1k; R_0603_1608Metric
R26, R27: 600; R_0603_1608Metric
R28: 13k; R_0603_1608Metric
SW1, SW2, SW3, SW4: SW_Push; FSMH
U1: RP2350_60QFN; RP2350-QFN-60-1EP_7x7_P0.4mm_EP3.4x3.4mm_ThermalVias
U2: W25Q128JVS; SOIC-8_5.3x5.3mm_P1.27mm
U4: RFM69HCW; MOD_COM-13909
U5: AP63203WU; TSOT-23-6
U6: 74AHCT1G125; SOT-25
U8: AP63205WU; TSOT-23-6
Y1: Crystal_GND24; ABM8272T3

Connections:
+1V1: C8.1, C10.1, C11.1, C12.1, L1.1, U1.6 (DVDD), U1.23 (DVDD), U1.39 (DVDD), U1.50 (VREG_FB)
+3V3: C1.1, C2.1, C3.1, C4.1, C5.1, C6.1, C7.1, C16.1, C20.1, C28.1, D2.2 (A), J1.1, J2.3, J4.2, J14.4 (VDD), JP1.2 (B), L2.1, R2.2, R3.2, R5.1, R10.1, R30.1, U1.1 (IOVDD), U1.11 (IOVDD), U1.20 (IOVDD), U1.30 (IOVDD), U1.38 (IOVDD), U1.44 (ADC_AVDD), U1.45 (IOVDD), U1.49 (VREG_VIN), U1.53 (USB_OTP_VDD), U1.54 (QSPI_IOVDD), U2.8 (VCC), U4.13 (3.3V), U5.1 (FB); also elsewhere on the board
+5V: C18.1, D3.1 (VDD), F2.2, J3.1, R21.1, U5.2 (EN), U5.3 (IN), U6.5 (VCC)
+5V_BUCK: C15.1, C25.1, IC1.6 (VIN2), L3.1, U8.1 (FB)
/5V_PIN14: J7.2, R31.2
/EN: IC3.2 (EN), R14.1
/GPIO0: J1.2, U1.2 (GPIO0)
/GPIO1: J1.3, U1.3 (GPIO1)
/GPIO2: J1.4, U1.4 (GPIO2)
/GPIO3: J1.5, U1.5 (GPIO3)
/GPIO4: J1.6, J2.1, J4.3, R12.2, U1.7 (GPIO4); also elsewhere on the board
/GPIO5: J1.7, J2.2, J4.4, R11.2, U1.8 (GPIO5); also elsewhere on the board
/GPIO6: J1.8, U1.9 (GPIO6)
/GPIO7: J1.9, U1.10 (GPIO7)
/GPIO8: J1.10, U1.12 (GPIO8)
/GPIO9: J1.11, J14.CD1, R30.2, U1.13 (GPIO9)
/GPIO10: J1.12, J14.5 (CLK), U1.14 (GPIO10)
/GPIO11: J1.13, J14.3 (CMD), U1.15 (GPIO11)
/GPIO12: J1.14, J14.7 (DAT0), U1.16 (GPIO12)
/GPIO13: J1.15, J14.2 (CD/DAT3), U1.17 (GPIO13)
/GPIO14: J1.16, R15.1, U1.18 (GPIO14)
/GPIO15: D3.4 (DIN), J1.17, U1.19 (GPIO15)
/GPIO16: J3.15, U1.27 (GPIO16), U4.2 (MISO)
/GPIO17: J3.14, R3.1, U1.28 (GPIO17), U4.5 (NSS); also elsewhere on the board
/GPIO18: J3.13, U1.29 (GPIO18), U4.4 (SCK)
/GPIO19: J3.12, U1.31 (GPIO19), U4.3 (MOSI)
/GPIO20: J3.11, U1.32 (GPIO20), U4.14 (DIO0)
/GPIO21: J3.10, R2.1, U1.33 (GPIO21), U4.6 (RESET); also elsewhere on the board
/GPIO22: J3.9, SW4.2, U1.34 (GPIO22)
/GPIO23: J3.8, SW3.2, U1.35 (GPIO23)
/GPIO24: J3.7, U1.36 (GPIO24)
/GPIO25: J3.6, R9.2, U1.37 (GPIO25)
/GPIO26_ADC0: J3.5, U1.40 (GPIO26_ADC0)
/GPIO27_ADC1: J3.4, U1.41 (GPIO27_ADC1)
/GPIO28_ADC2: J3.3, U1.42 (GPIO28_ADC2)
/GPIO29_ADC3: J3.2, U1.43 (GPIO29_ADC3)
/QSPI_SCLK: U1.56 (QSPI_SCLK), U2.6 (CLK)
/QSPI_SD0: U1.57 (QSPI_SD0), U2.5 (DI/IO_{0})
/QSPI_SD1: U1.59 (QSPI_SD1), U2.2 (DO/IO_{1})
/QSPI_SD2: U1.58 (QSPI_SD2), U2.3 (~WP/IO_{2})
/QSPI_SD3: U1.55 (QSPI_SD3), U2.7 (~HOLD/~RESET/IO_{3})
/QSPI_SS: R6.1, R10.2, U1.60 (QSPI_SS), U2.1 (~CS)
/RUN: J3.16, SW2.2, U1.26 (RUN)
/SWCLK: J3.18, J10.1, U1.24 (SWCLK)
/SWD: J3.17, J10.3, U1.25 (SWD)
/USB_N: J11.A7 (DN1), J11.B7 (DN2), J13.3, R8.1
/USB_P: J11.A6 (DP1), J11.B6 (DP2), J13.2, R7.1
/VREG_AVDD: C9.1, R5.2, U1.46 (VREG_AVDD)
/VREG_LX: L1.2, U1.48 (VREG_LX)
/XIN: C13.1, U1.21 (XIN), Y1.1
/XOUT: R1.1, U1.22 (XOUT)
EXTPOWER: J6.1, J12.1, J12.3
EXT_FUSED: C23.1, J7.3, J12.2, J12.4, U8.2 (EN), U8.3 (IN)
GND: C1.2, C2.2, C3.2, C4.2, C5.2, C6.2, C7.2, C8.2, C9.2, C10.2, C11.2, C12.2, C13.2, C14.2, C15.2, C16.2, C17.2, C18.2, C20.2, C21.2, C22.2, C23.2, C25.2, C26.2, C27.2, C28.2, D1.1 (K), D3.3 (VSS), IC1.1 (GND_1), IC1.4 (~ON), IC1.5 (GND_2), IC2.4 (~CE), IC2.5 (GND), IC2.11 (EP), IC3.4 (GND), J1.18, J2.4, J4.1, J6.2, J7.1, J8.2 (Ext), J9.2, J10.2, J11.A1 (GND_1), J11.A12 (GND_2), J13.1, J14.6 (VSS), J14.G1 (GND_1), J14.G2 (GND_2), J14.G3 (GND_3), J14.G4 (GND_4), JP2.2 (B), JP3.2 (B), R4.2, R17.1, R18.1, R19.2, R27.1, R28.1, R29.1, SW1.1, SW3.1, SW4.1, U1.47 (VREG_PGND), U1.61 (GND), U2.4 (GND), U4.1 (GND), U4.8 (GND), U4.10 (GND), U5.4 (GND), U6.1, U6.3 (GND), U8.4 (GND), Y1.2, Y1.4
unnamed: C14.1, R1.2, Y1.3
unnamed: CHG1.1 (K), R24.2
unnamed: D1.2 (A), R9.1
unnamed: D2.1 (K), R13.2
unnamed: Fault1.1 (K), R25.2
unnamed: IC1.8 (ST), R21.2
unnamed: C26.1, F2.1, IC1.2 (VOUT_1), IC1.7 (VOUT_2)
unnamed: IC2.7 (ILIM/VSET), R28.2
unnamed: IC2.8 (ISET), R26.2, R27.2
unnamed: IC2.9 (STAT1), R25.1
unnamed: IC2.3 (STAT2), R24.1
unnamed: IC2.6 (TS/MR), R29.2
unnamed: IC3.1 (FB), R16.1, R17.2
unnamed: IC3.5 (SW), L4.1
unnamed: J5.1, J8.1 (In), U4.9 (ANT)
unnamed: J11.A5 (CC1), R19.1
unnamed: J11.B5 (CC2), R18.2
unnamed 71: JP1.1 (A), R11.1, R12.1; also elsewhere on the board
unnamed: JP2.1 (A), R13.1
unnamed: JP3.1 (A), R26.1
unnamed: R4.1, SW2.1
unnamed: R6.2, SW1.2
unnamed: R15.2, U6.2
unnamed: R31.1, U6.4
unnamed: R8.2, U1.51 (USB_DM)
unnamed: R7.2, U1.52 (USB_DP)
unnamed: C19.1, U5.6 (BST)
unnamed: C19.2, L2.2, U5.5 (SW)
unnamed: C24.1, U8.6 (BST)
unnamed: C24.2, L3.2, U8.5 (SW)
VBAT: IC2.2 (BAT), J9.1
VBUS: C27.1, IC2.10 (IN), J11.A4 (VBUS_1), J11.A9 (VBUS_2), J13.4
VSYS: C22.1, CHG1.2 (A), Fault1.2 (A), IC2.1 (SYS), IC3.3 (VIN), L4.2, R14.2
VSYS_5V: C17.1, C21.1, IC1.3 (VIN1), IC3.6 (VOUT), R16.2

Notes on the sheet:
Flash
Power Indicator
Lipo
5V BUCK
Make sure R7 and R8 are close to RP2350
12MHz Crystal
Onboard LED
Debug
RFM69
6-30V External Power Source Conntected at the terminals
QWIIC
NEOPIXAL
RESET
LED Strip
User Buttons
External Power
5-18V Solar can be used on VIN. Don't plug in USB connector at the same time.
OLED/I2C
IOs
Use the internal pullup resistors
BOOTSEL
3.3V Power

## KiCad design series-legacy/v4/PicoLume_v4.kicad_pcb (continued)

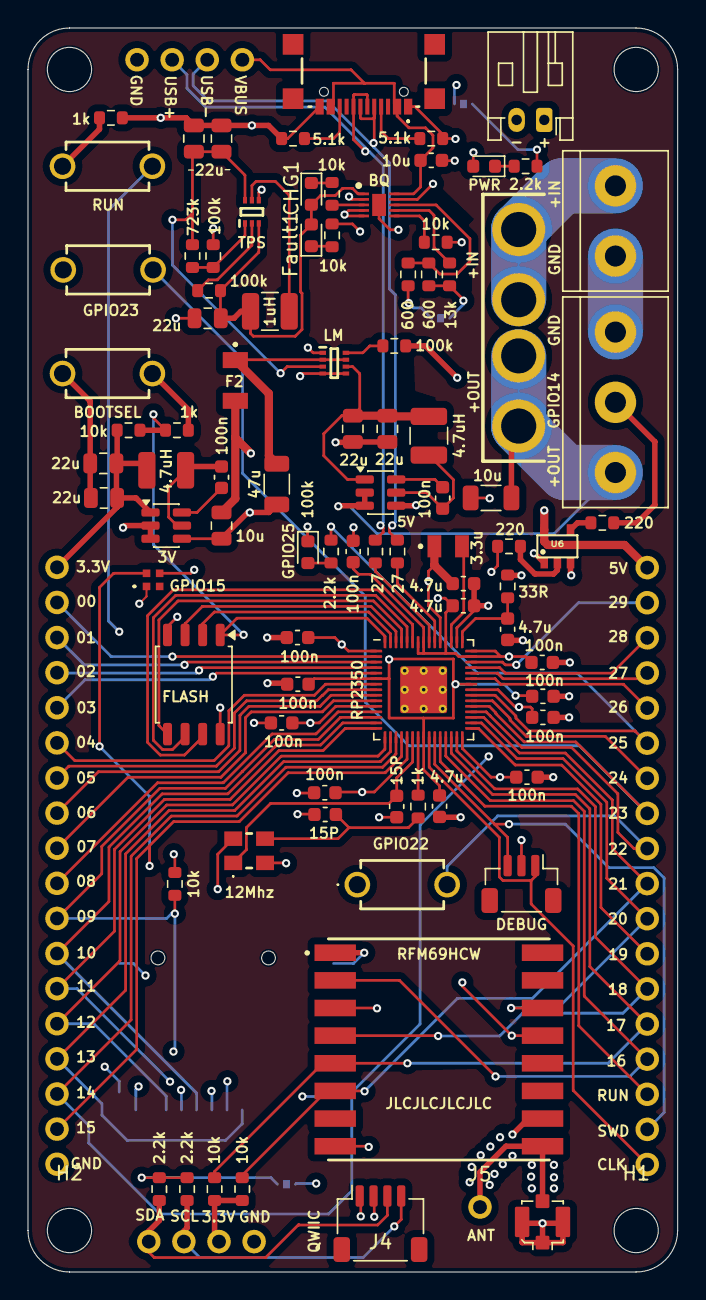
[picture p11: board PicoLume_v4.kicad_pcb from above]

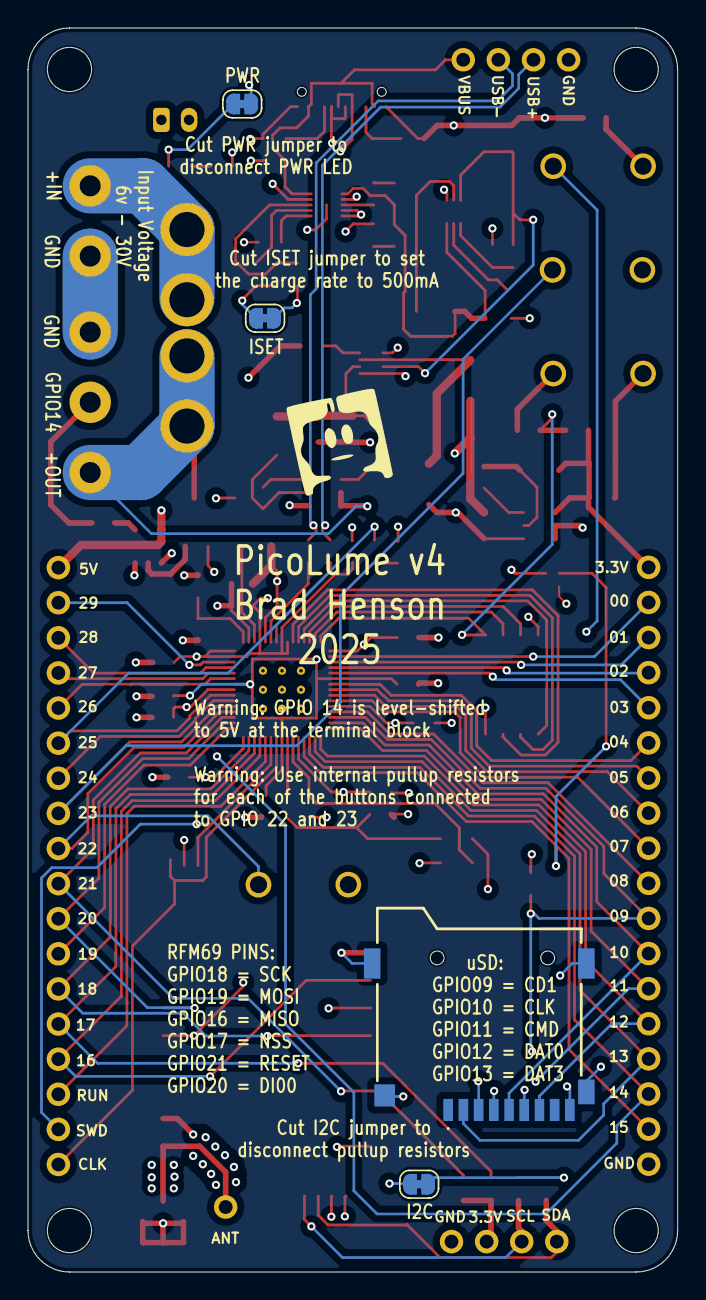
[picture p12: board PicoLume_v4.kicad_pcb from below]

Board: 4 copper layers, 47.0 x 90.0 mm, 101 parts (4 on the bottom side), 88 nets.

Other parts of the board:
2.2k, 2.2k#2: 2.2k; R_0603_1608Metric
10k, 10k#2: 10k; R_0603_1608Metric

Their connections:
+3V3: 10k.2, 10k#2.2; also elsewhere on the board
/GPIO4: 2.2k.2; also elsewhere on the board
/GPIO5: 2.2k#2.2; also elsewhere on the board
/GPIO17: 10k.1; also elsewhere on the board
/GPIO21: 10k#2.1; also elsewhere on the board
unnamed 71: 2.2k.1, 2.2k#2.1; also elsewhere on the board

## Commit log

2025-12-16 Initial commit: PicoLume Hardware KiCad projects
    Includes:
    - series-legacy: v1-v4 board designs
    - series-prop: receiver-v1 design
    - series-mini: placeholder for future designs
    [3544-2.stp, 53261-0271.stp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]
2025-12-18 Removed bulk output cap and added PTC on VBAT input
    [PicoLume_Receiver.kicad_pcb, PicoLume_Receiver.kicad_sch]
2025-12-19 deleted empty folder for undeveloped board
2025-12-19 removed reference to the mini board
2025-12-23 replaced the RGB led with a button on GPIO15
    [PicoLume_Receiver.kicad_pcb, PicoLume_Receiver.kicad_sch]
2025-12-23 renamed prop receiver from v1 to v0.1.0
    [3544-2.stp, LM66200DRLR.stp, RFM69HCW.STEP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]
2025-12-24 added remote design files
    [3544-2.stp, LM66200DRLR.stp, RFM69HCW.STEP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]
